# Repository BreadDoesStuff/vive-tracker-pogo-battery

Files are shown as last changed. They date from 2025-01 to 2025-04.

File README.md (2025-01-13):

# Vive Tracker Pogo Pin Battery Puck - V2.0

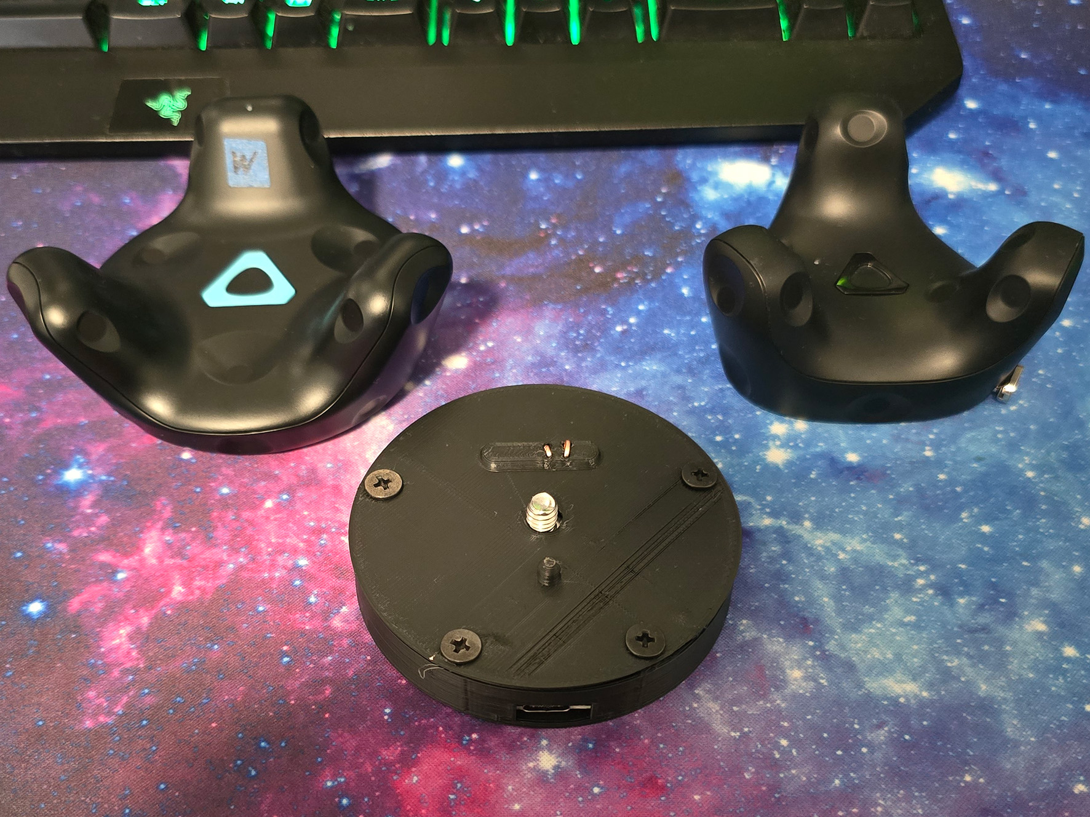
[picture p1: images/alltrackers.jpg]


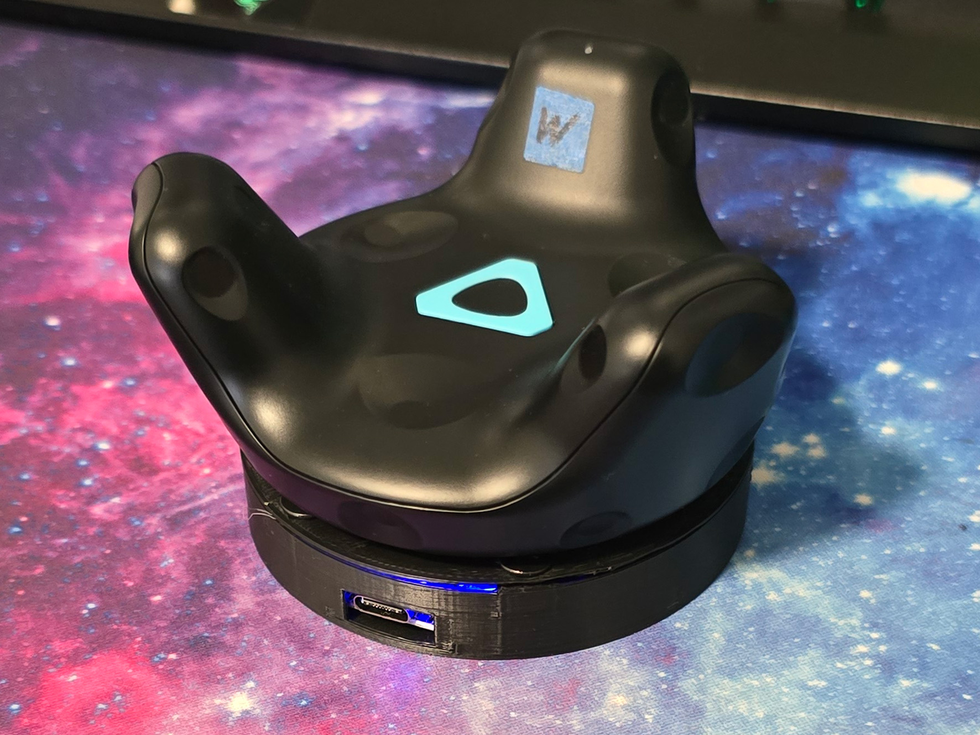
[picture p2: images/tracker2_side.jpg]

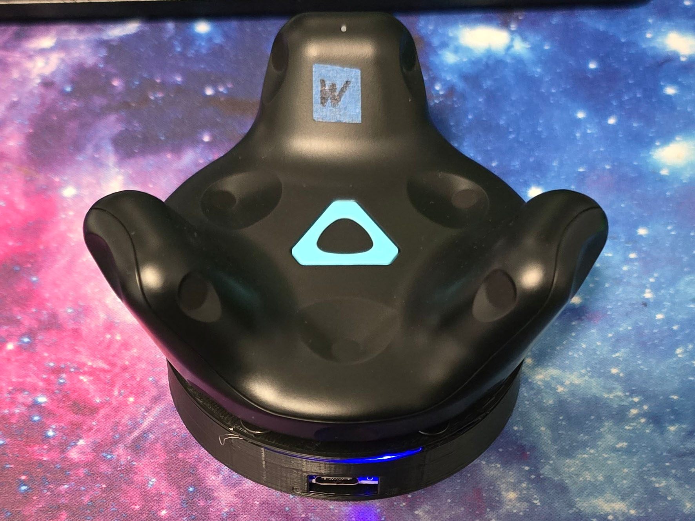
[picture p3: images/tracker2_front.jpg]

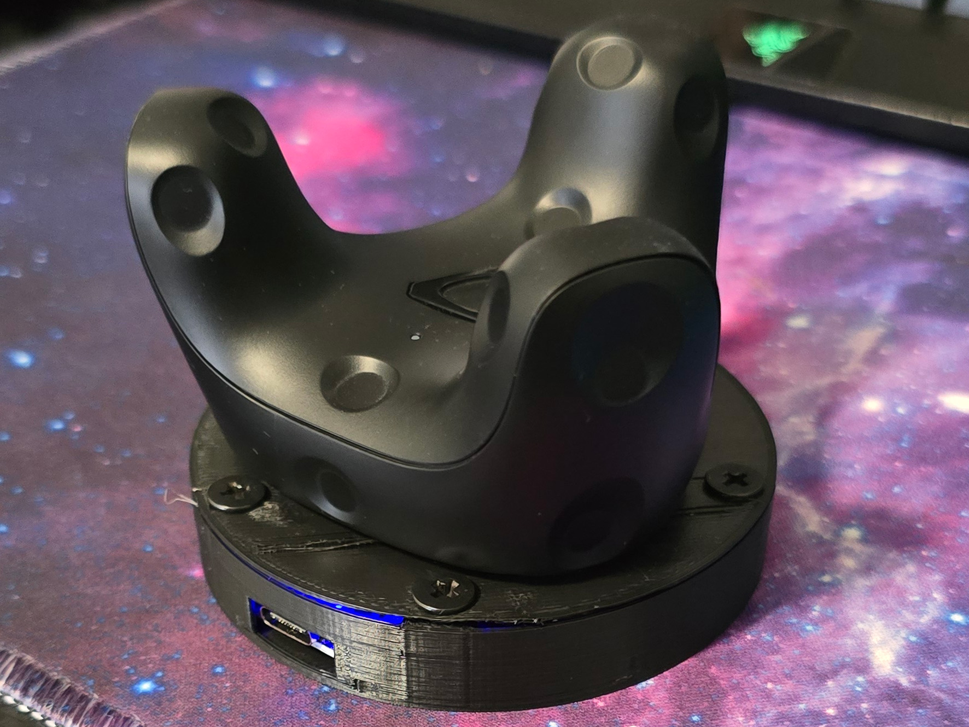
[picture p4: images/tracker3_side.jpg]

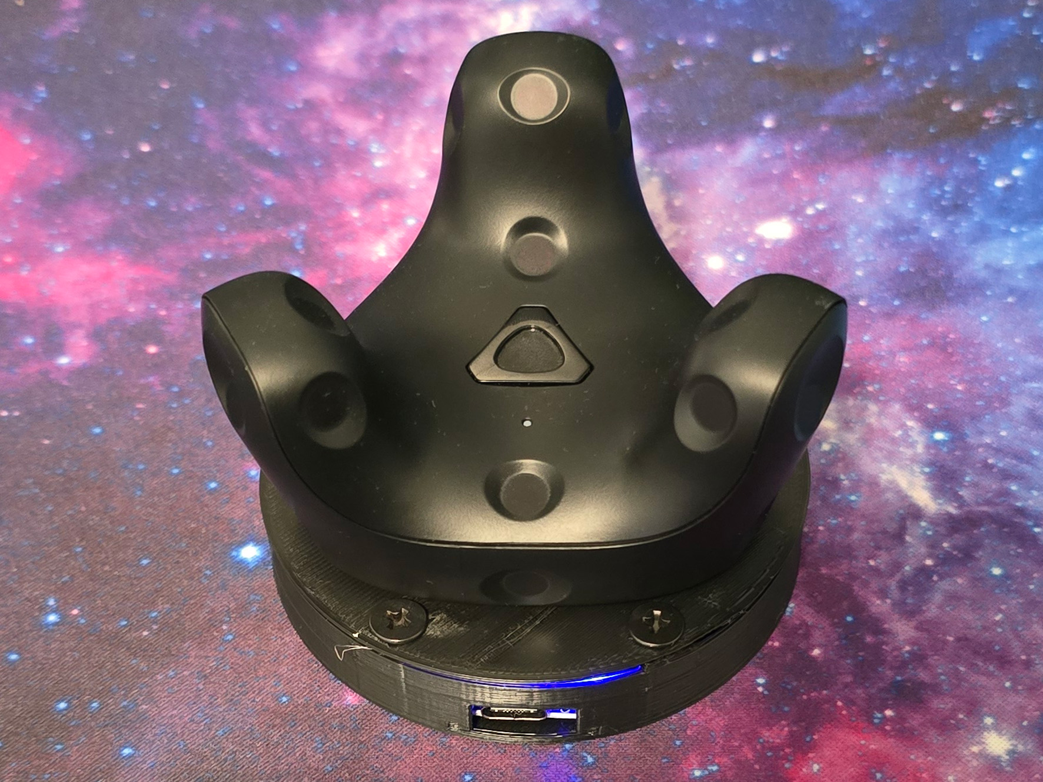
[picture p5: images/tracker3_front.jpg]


A Vive Tracker Battery Puck that charges the tracker through pogo pins. Compatible with both Vive Tracker 3.0 and 2.0.

Has a total capacity of 2,000mAh which:

Adds 10 additional hours of usage for the 2.0 Tracker.

Adds 20 additional hours of usage for the 3.0 Tracker.

# [CHANGELOG](CHANGELOG.md) 

# [BUILD INSTRUCTIONS](INSTRUCTIONS.md)

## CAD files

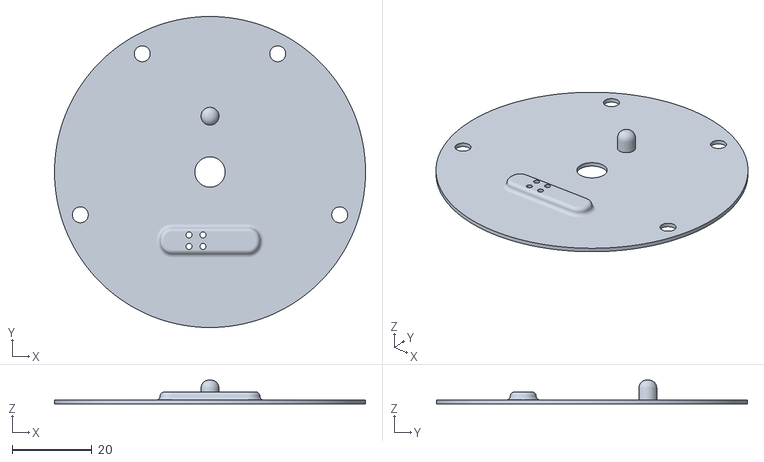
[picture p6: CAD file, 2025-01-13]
stl/TopLidBase.stl
78.0 x 78.0 x 6.00

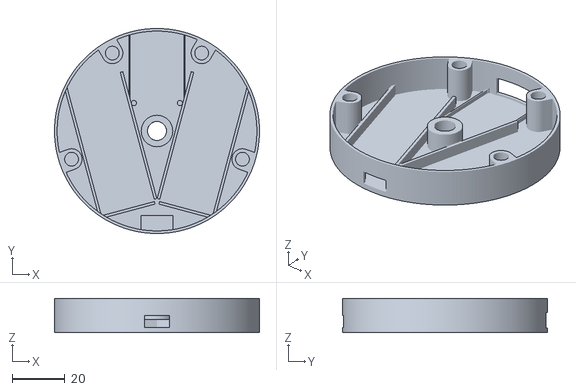
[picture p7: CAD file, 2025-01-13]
stl/LowerCase.stl
78.0 x 78.0 x 13.0

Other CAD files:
source/ViveTrackerPogoBatteryV2.f3d

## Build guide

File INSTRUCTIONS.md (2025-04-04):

# Instructions
Here's how you can build your own Vive Tracker Pogo Pin Battery Puck.

# DISCLAIMER
I am not responsible for any damage, fires, or injuries that may occur during assembly. Please be careful when handling Lithium Polymer batteries.

Don't connect batteries in series. Make sure they are connected **parallel** (Positive to Positive, Negative to Negative) **ONLY** when the batteries have less than a <ins>**0.2v difference.**</ins>

## Tools Required

- 3D Printer
- Soldering Iron (Recommended: Threaded brass insert tips)
- Hot Glue Gun
- Multi-Meter
- Small Flathead Screwdriver
- Long Phillips Screwdriver with a thin shaft
- Wire Stripper
- Pliers
- Lighter (or heat gun)

## Components List (For one Puck)

1x SS12D00 Interruptor Switch - 
https://www.aliexpress.com/item/3256805447103314.html

2x 102050 3.7v LiPO Battery (10 * 20 * 50mm) - 
https://www.aliexpress.us/item/3256805815224609.html

1x 5V 2A Boost Converter w/ Battery Charging Circuit (Without the USB Ports Soldered) - 
https://www.aliexpress.us/item/3256805822783483.html

1x 1/4"-20 Brass Insert Thread (Through Hole) - 
https://www.aliexpress.us/item/3256804959215874.html

22 AWG Wire - 
https://www.aliexpress.us/item/3256804688199892.html

4x M4 8mm length Flat Head Phillips - 
https://www.aliexpress.us/item/3256805491375836.html

1x 1/4-20 5/16" Length Phillips Pan Head Screw - 
https://www.aliexpress.us/item/3256801440856024.html

3M VHB Adhesive Tape - 
https://www.amazon.com/gp/product/B07TC16SZ7/

Bare Copper Wire (16 AWG)

## Printing

LowerCase
TopLidBase

Print with 20% Infill. No supports. PLA is fine.

## Case Prep

Insert the brass threads into the case, 1 for the tracker screw at the bottom of the case and 4 at the top of the case.

Insert a small U-shaped length of copper wire into the top lid holes to be used as contacts. If it doesn't fit, heat up some steel wire or copper wire to space out the hole.

## Wiring

2x 1000mAh batteries connected in parallel > Charging Module > Charging Module 5V Out > Switch > Copper Contacts (Inserted through the lid)

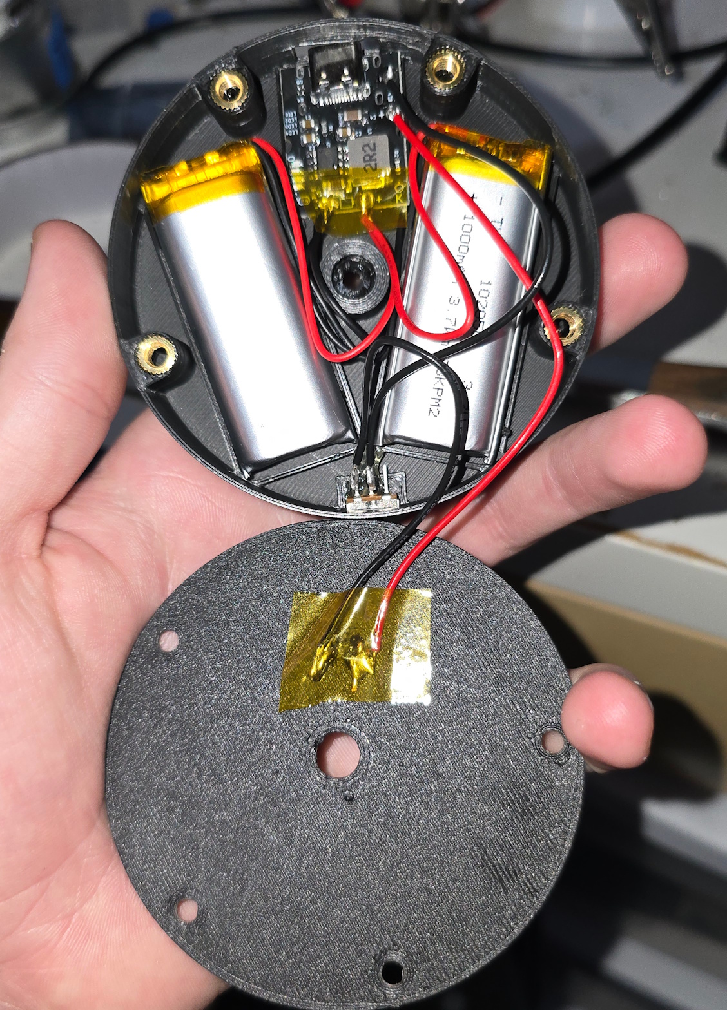
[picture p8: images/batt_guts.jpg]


Vive Tracker Pinout Reference

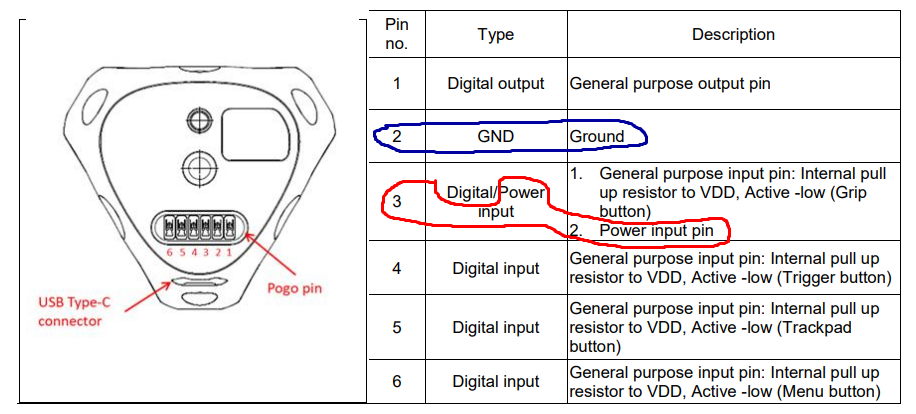
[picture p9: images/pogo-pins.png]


## Securing the Components

Hot glue the switch and charging module in place. Batteries will be secured with VHB tape adhered to the bottom of the case.

## Attaching the Tracker

Once the puck has been fully assembled, insert a long thin philips screwdriver into the thread insert hole at the bottom of the battery bank to screw the mounting screw into the tracker.

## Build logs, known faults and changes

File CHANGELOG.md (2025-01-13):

# Changelog

## V2
Initial V2 Release
Features a smaller, thinner, and simpler design compared to V1.

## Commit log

2023-12-11 Initial Release?? I think?
    Here it goesss
    [ViveTrackerPogoBatteryV1-Case.stl, ViveTrackerPogoBatteryV1-Lid.stl, ViveTrackerPogoBatteryV1.FCStd]
2023-12-11 Fixed formatting and added objs
    [ViveTrackerPogoBatteryV1-Case.obj, ViveTrackerPogoBatteryV1-Lid.obj]
2025-01-13 V2 Initial Release
    [LowerCase.stl, TopLidBase.stl, ViveTrackerPogoBatteryV1-Case.obj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]
2025-01-13 Update README.md
    Added the current revision number
